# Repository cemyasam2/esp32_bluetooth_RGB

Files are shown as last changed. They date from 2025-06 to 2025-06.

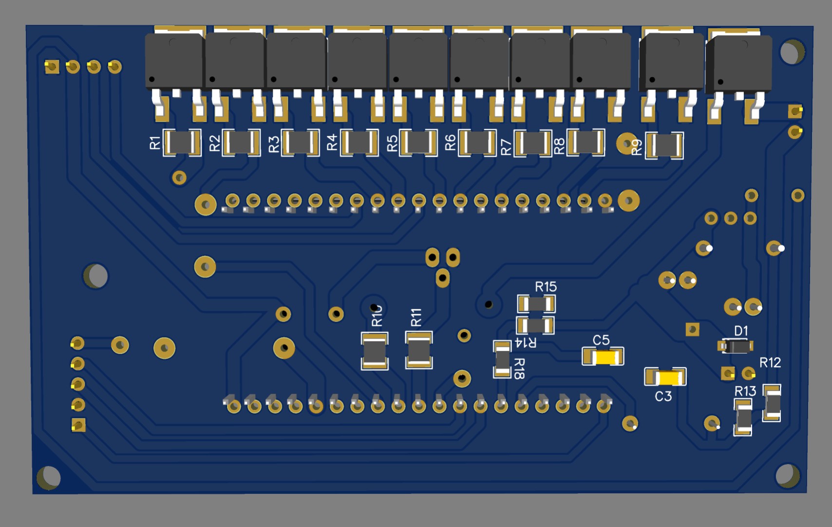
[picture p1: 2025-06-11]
boardback.jpg

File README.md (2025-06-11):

# 💡 esp32 LED Animasyon Projesi

Bu proje, esp32 kullanarak RGB LED’ler üzerinde animasyonlar oluşturur.  
Rotary encoder ile animasyonlar arasında geçiş yapılabilir. OLED ekran ve EEPROM desteği ile tam bir görsel deneyim sağlar! bluetooth üzerinden android telefonlar ile kontrol edilebnilir.
aşşagıdaki adresteki app ile kontrol edilebilir.

https://play.google.com/store/apps/details?id=easy.tech.rgbledcontrol&hl=tr

## 🎥 YouTube Videosu
👉 [Projeyi buradan izleyebilirsin](https://www.youtube.com/shorts/8XcT7dM-Kzo)

---

## 🔧 Kullanılan Malzemeler
-  ESP32
- 170cm RGB LED
- 1x Rotary Encoder
- 0.96" OLED Ekran (I2C)
- rotary encoder
- EEPROM (dahili)
- 3D baskı kutu (dosya eklidir)
ID	Name	Designator	Footprint	Quantity	Manufacturer Part	Manufacturer	Supplier	Supplier Part	Price
"1"	"10K"	"R16"	"R_AXIAL-0.4"	"1"	""	""	""	""	""
"2"	"1N4007"	"D2"	"DO-41_BD2.4-L4.7-P8.70-D0.9-RD"	"1"	"1N4007"	"SEMTECH"	"LCSC"	"C106903"	"0.019"
"3"	"H2"	"OLEDEKRAN"	"HDR-F-2.54_1X4"	"1"	""	""	"LCSC"	"C225501"	"0.077"
"4"	"H1"	"ROTARYSWITCH"	"HDR-F-2.54_1X5"	"1"	""	""	"LCSC"	"C50950"	"0.064"
"5"	"HDR-F-2.54_1x2"	"CHARGE_IN,POWER"	"HDR-F-2.54_1X2"	"2"	""	""	"LCSC"	"C49661"	"0.038"
"6"	"BC547"	"Q10"	"BC547"	"1"	""	""	""	""	""
"7"	"BUZZER"	"SG1"	"BUZZER-12MM"	"1"	""	""	""	""	""
"8"	"L7805"	"U1"	"L7803"	"1"	""	""	""	""	""
"9"	"ESP32 DEVKIT"	"U2"	"ESP32DEVKITCV4"	"1"	"ESP32 Dev Kit C V4"	"AZ-DELIVERY"	""	""	""
"10"	"200U"	"C1,C2"	"CAP-D6.3×F2.5"	"2"	""	""	""	""	""
"11"	"100NF"	"C3,C5"	"C1206"	"2"	""	""	""	""	""
"12"	"1N4007W"	"D1"	"SOD-123_L2.8-W1.8-LS3.7-RD"	"1"	"1N4007W"	"BLUE ROCKET"	"LCSC"	"C328592"	"0.008"
"13"	"22k"	"R12,R14"	"R1206"	"2"	""	""	""	""	""
"14"	"5k"	"R13,R15"	"R1206"	"2"	""	""	""	""	""
"15"	"10k"	"R18"	"R1206"	"1"	""	""	""	""	""
"16"	"1k"	"R1,R2,R3,R4,R5,R6,R7,R8,R9,R10,R11"	"R1210"	"11"	""	""	""	""	""
"17"	"NJVMJD122T4G"	"Q1,Q2,Q3,Q4,Q5,Q6,Q7,Q8,Q9,Q12"	"DPAK-3"	"10"	""	""	""	""	""

---

## 🧠 Özellikler
- Renk geçişli animasyonlar
- Encoder ile geçiş kontrolü
- EEPROM’a ayar kaydı
- Şarj durumu takibi
- OLED'de animasyon & pil simgeleri
- bluetooth kontrol

---

## 🖥️ Kod
Ana kod dosyasını `esp32_bluetooth_RGB_.ino` olarak yükleyebilirsin.  

---

## 🖨️ 3D Dosyalar
-[📦 STL dosyasını indir](difizor.stl)
-[📦 STL dosyasını indir](difizorbitis baslangic.stl)
-[📦 STL dosyasını indir](halka ek.stl)
-[📦 STL dosyasını indir](led tutucu.stl)
-[📦 STL dosyasını indir](rgb dikey lamba atma.stl)
-[📦 STL dosyasını indir](rotary tutucua.stl)
-[📦 STL dosyasını indir](taban kapak lamba.stl)
-[📦 STL dosyasını indir](taban.stl)

## 🔌 Devre Şeması
- topprint.pdf
- top.pdf
- back.pdf
- Gerber_rgbcubuk2_PCB_rgbcubuk2_2025-06-11.zip
- boardback.jpg
- boardfront.jpg
- BOM_rgbcubuk2_2025-06-11.csv
- PickAndPlace_PCB_rgbcubuk2_2025-06-11.csv

## 📄 Lisans
MIT Lisansı altında paylaşılmıştır. Dilediğiniz gibi kullanabilirsiniz.

---

## ☕ Destek Ol
Eğer projeyi beğendiysen, YouTube kanalıma abone olmayı unutma!  
[👉 TinkTime YouTube Kanalı](https://www.youtube.com/@cemyasamaka)

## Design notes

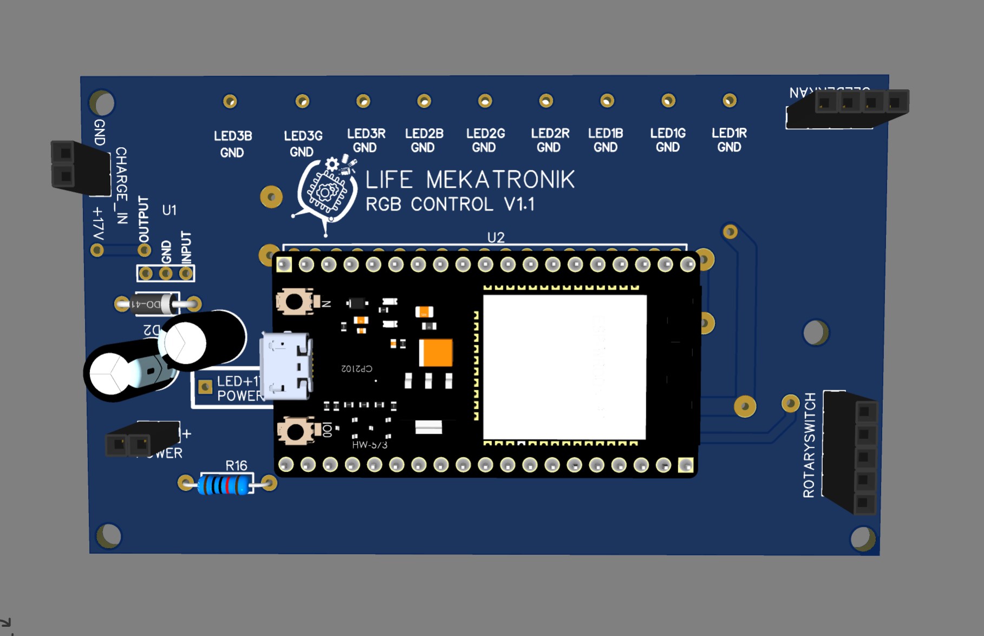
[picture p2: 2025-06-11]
boardfront.jpg

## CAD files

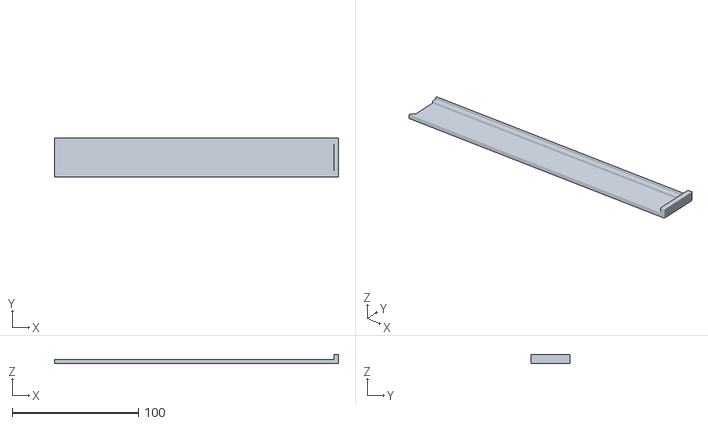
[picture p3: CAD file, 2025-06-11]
difizorbitis baslangic.stl
225.2 x 31.2 x 7.00

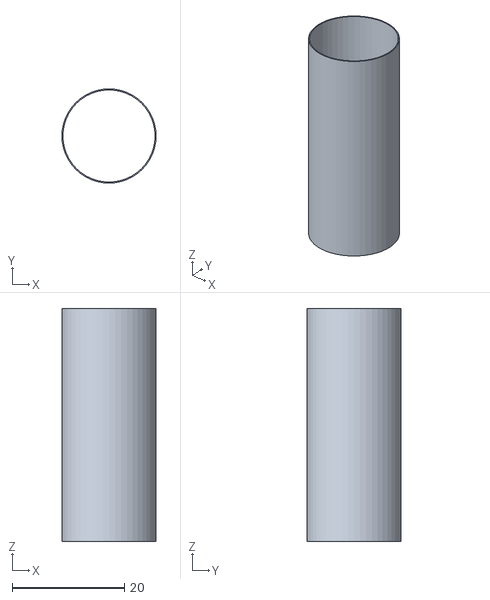
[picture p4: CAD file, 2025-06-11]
halka ek.stl
16.8 x 16.8 x 41.5

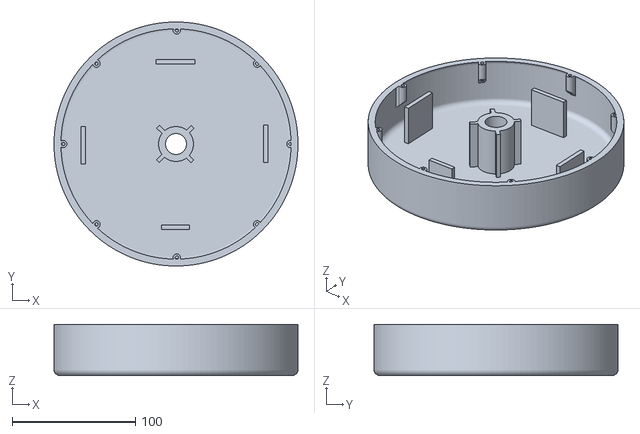
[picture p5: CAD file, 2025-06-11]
taban.stl
198.0 x 198.0 x 41.5

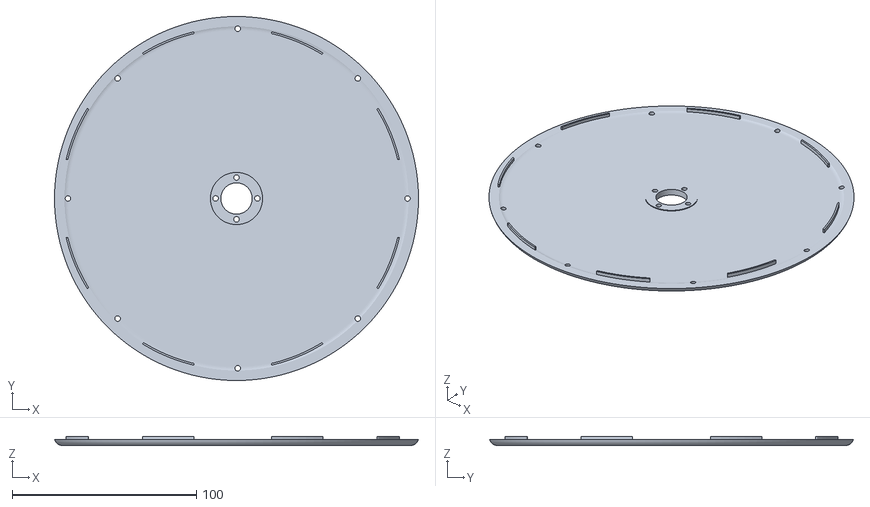
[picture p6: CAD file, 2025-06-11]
taban kapak lamba.stl
197.7 x 197.7 x 5.15

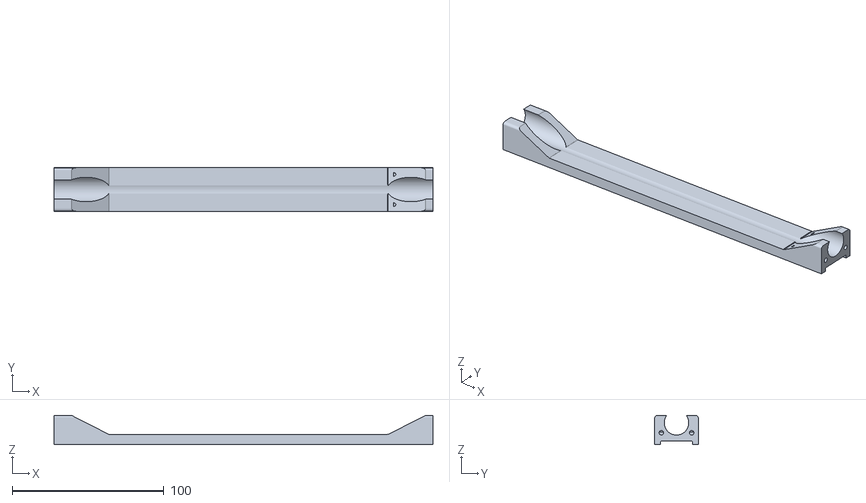
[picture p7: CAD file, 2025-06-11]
led tutucu.stl
250.0 x 28.7 x 19.4

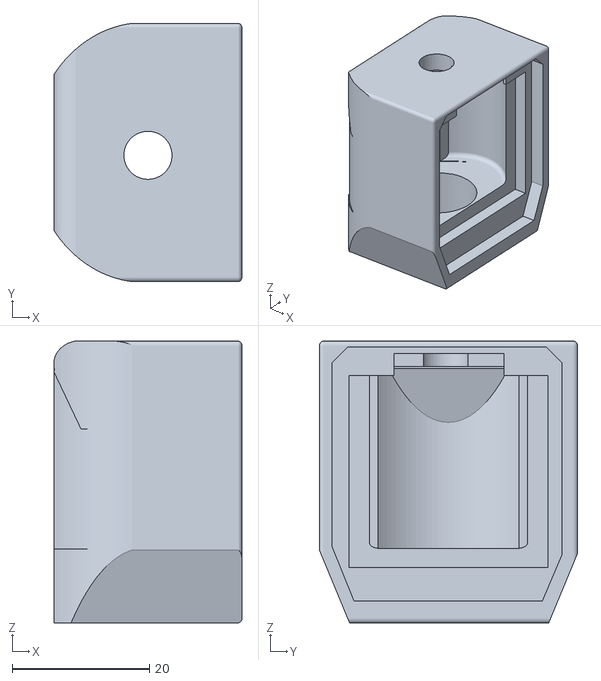
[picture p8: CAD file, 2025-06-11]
rotary tutucua.stl
27.4 x 37.6 x 41.1

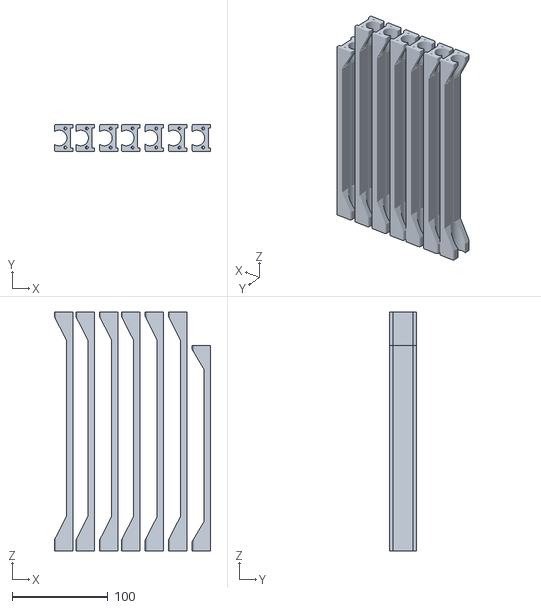
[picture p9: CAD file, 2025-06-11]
rgb dikey lamba atma.stl
163.5 x 28.7 x 250.0

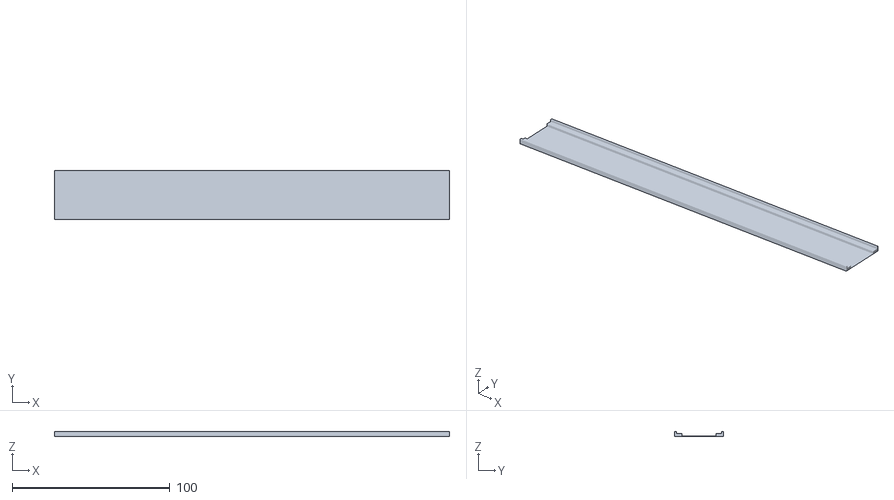
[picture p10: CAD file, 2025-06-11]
difizor.stl
250.2 x 31.2 x 3.24

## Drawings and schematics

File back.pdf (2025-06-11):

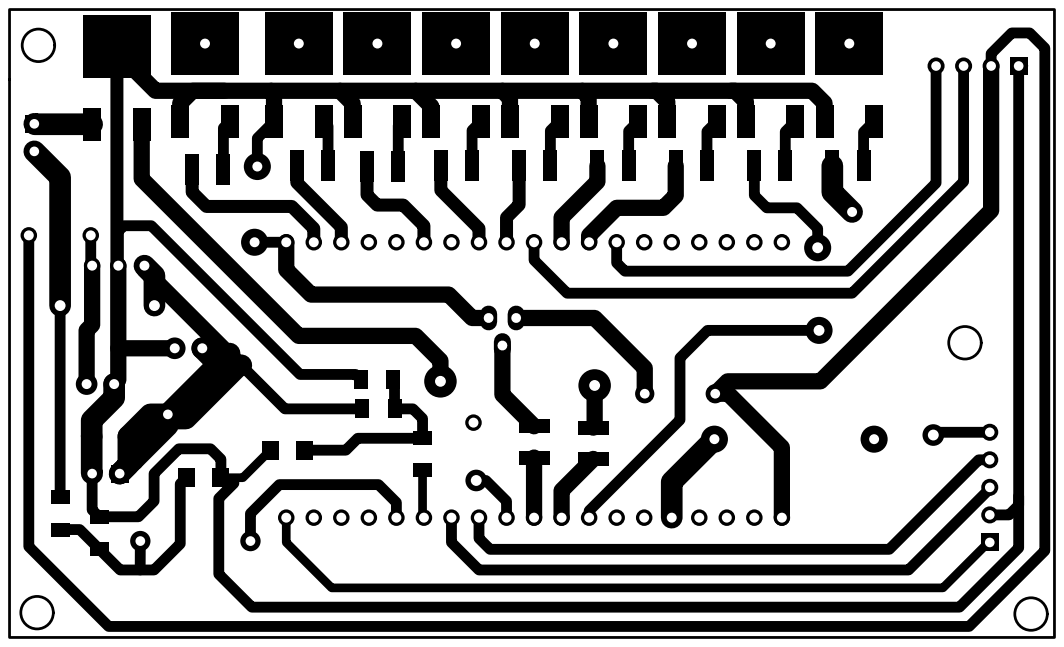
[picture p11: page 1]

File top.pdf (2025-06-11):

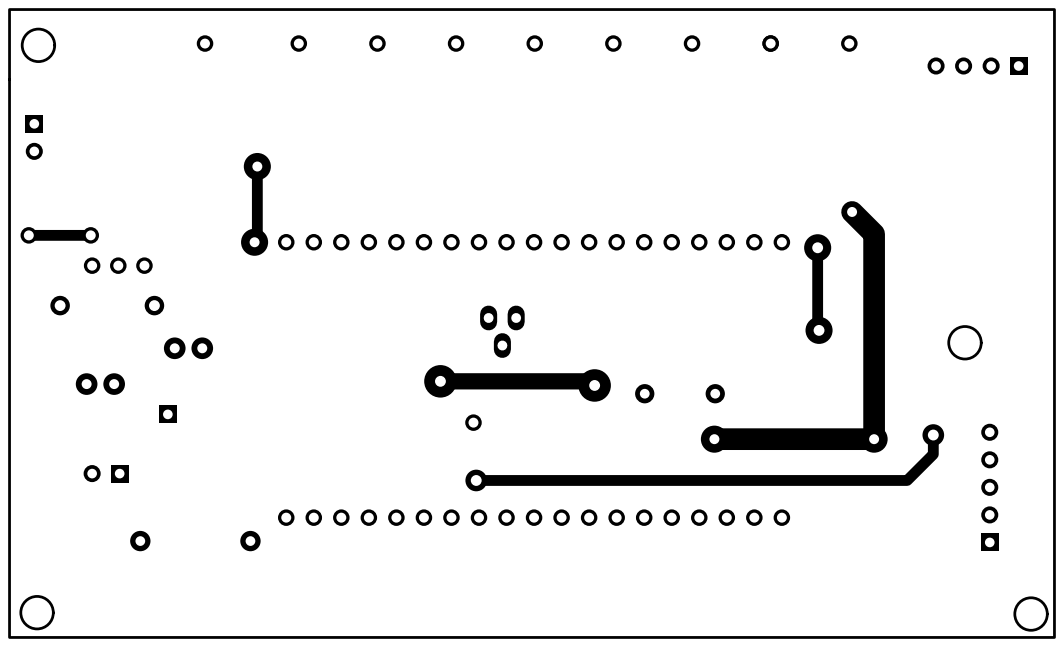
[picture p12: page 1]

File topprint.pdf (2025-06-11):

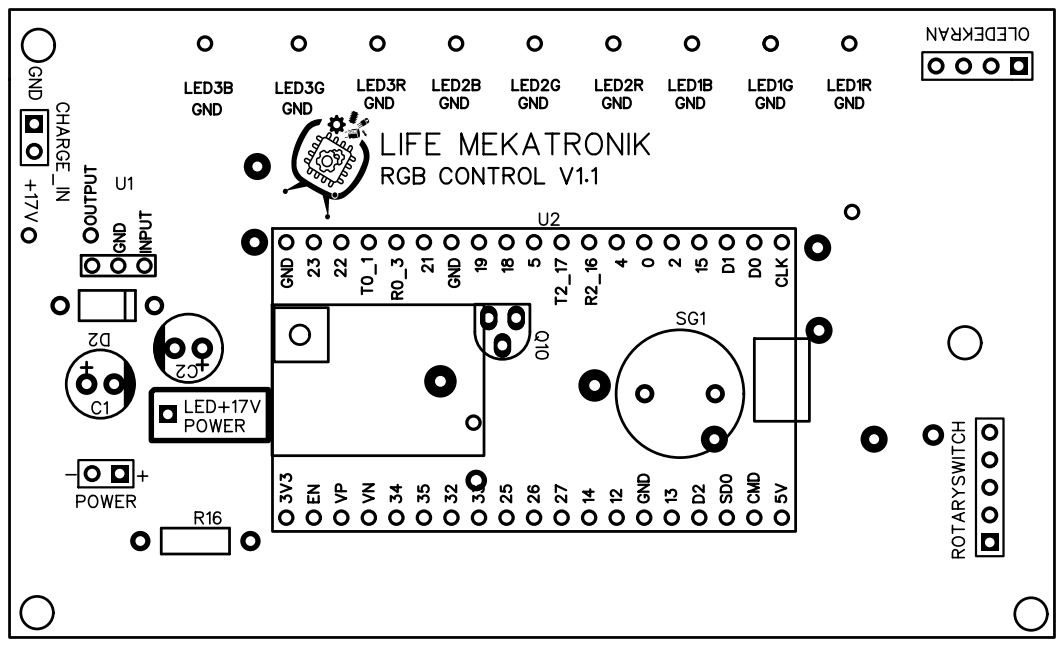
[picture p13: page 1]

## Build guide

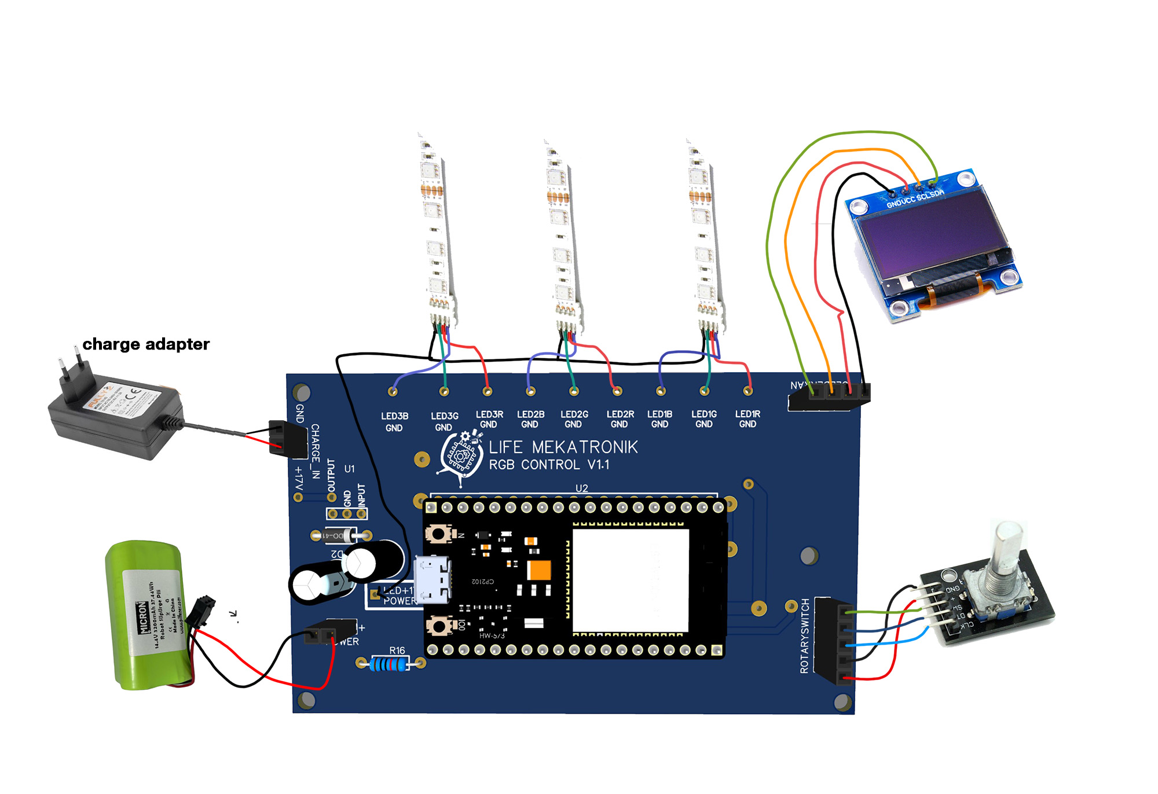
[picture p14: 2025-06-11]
wiring schema.jpg

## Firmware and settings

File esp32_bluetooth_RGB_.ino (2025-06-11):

#include <Wire.h>
#include <EEPROM.h>
#include <Adafruit_GFX.h>
#include <Adafruit_SSD1306.h>
#include "BluetoothSerial.h" // Bluetooth seri haberleşme kütüphanesi
// Wi-Fi ve OTA etkinlik kontrol değişkenleri
#define WIFI_ENABLED  0  // 1: WiFi açık,  0: WiFi kapalı

#if WIFI_ENABLED
#include <WiFi.h>
#include <WebServer.h>
#include <ElegantOTA.h>

// Wi-Fi ayarları
const char* ssid = "wifi ag adı yazın"; // Wi-Fi ağ adı
const char* password = "wifi şifrenizi yazın"; // Wi-Fi şifresi
// Sabit IP ayarları
IPAddress local_IP(192, 168, 1, 12);  // Sabit IP adresi
IPAddress gateway(192, 168, 1, 1);    // Ağ geçidi (genellikle router IP'si)
IPAddress subnet(255, 255, 255, 0);   // Alt ağ maskesi


WebServer server(80); // Web sunucusu 80 numaralı portt


#endif // WIFI_ENABLED


// === OLED ===
#define SCREEN_WIDTH 128
#define SCREEN_HEIGHT 64
#define OLED_SDA 4
#define OLED_SCL 5
Adafruit_SSD1306 display(SCREEN_WIDTH, SCREEN_HEIGHT, &Wire, -1);

// === PINLER ===
#define ENCODER_PIN_A 32
#define ENCODER_PIN_B 33
#define ENCODER_BUTTON 25
#define BUZZER_PIN 26
#define charge_on_of 27
#define BATTERY_ADC_PIN 35
#define LOW_VOLTAGE_THRESHOLD 11.0 // Batarya tipinize göre güncelleyin
#define CHARGE_ADC_PIN 34
#define CHARGE_PRESENT_THRESHOLD 3.0 // Gerilim bölücüye göre ayarla (adaptörün voltajını böldükten sonra bu pindeki voltaj eşiği)

const uint8_t pwmPins[3][3] = {
  {16, 14, 13}, {19, 18, 17}, {23, 22, 21}
};
const uint8_t pwmChannels[3][3] = {
  {2, 1, 0}, {5, 4, 3}, {8, 7, 6}
};

// === EEPROM ===
#define EEPROM_SIZE 7
int hueAddr[3] = {0, 2, 4};
int brightnessAddr[3] = {1, 3, 5};
#define GROUP_ADDR 6

// === Kontrol Değişkenleri ===
int animationSpeed = 30; // Genel animasyon hızı
int hue[3] = {0, 0, 0};
float brightness[3] = {1.0, 1.0, 1.0};
int selectedGroup = -1; // -1: Tümü, 0-2: Grup 1-3, 3-7: Animasyonlar, 8: Bluetooth Renk Modu

volatile int encoderPos = 0;
int lastEncoderPos = 0;
int lastEncoded = 0;
unsigned long lastEncoderTime = 0;
unsigned long lastDisplayUpdate = 0;
unsigned long lastRainbowUpdate = 0;
unsigned long buttonPressTime = 0;
bool buttonPressed = false;
bool longPressHandled = false;
bool longPressCandidate = false;

bool chargingDisplayActive = false; // Batarya şarj ekranı aktif mi?
bool chargingDisplaySuppressed = false; // Batarya şarj ekranı kullanıcı tarafından gizlendi mi?

// Animasyonlar için durum değişkenleri
unsigned long lastAnimationTime = 0;
int currentGroup = 0;         // Kayar animasyonlarda hangi grubun sırası
int currentColorPhase = 0; // Kayar animasyonlarda 0: Kırmızı, 1: Mavi, 2: Yeşil
const int ON = 255;         // On/Off modu için tam parlaklık
const int OFF = 0;          // On/Off modu için kapalı
const int MAX_BRIGHTNESS_VAL = 255; // İz bırakan animasyon için tam parlaklık
const int MIN_BRIGHTNESS_VAL = 0;   // İz bırakan animasyon için kapalı
const int FADE_STEP = 10;         // İz bırakan animasyonda sönme adım miktarı
const unsigned long FADE_INTERVAL = 3; // İz bırakma sönme hızı (ms)

// Her grubun o anki renk değerlerini tutan değişkenler (fade için önemli)
int currentRGB[3][3] = {{0, 0, 0}, {0, 0, 0}, {0, 0, 0}}; // [grup][kanal]

// İz bırakan animasyon için değişkenler
unsigned long lastFadeTime[3] = {0, 0, 0}; // Her grubun son sönme zamanı
bool fading[3] = {false, false, false};   // Her grup sönüyor mu?

// === Bluetooth ===
BluetoothSerial SerialBT;
bool isBluetoothConnected = false; // Bluetooth bağlantı durumu
bool bluetoothColorMode = false;   // Bluetooth ile renk ayarı yapılıp yapılmadığını takip et

// === Fonksiyon Prototipleri ===
void updateDisplay();
void applyAllColors();
void allGroupsOff();
void startFadeOut(int group);
void handleFading();
void setGroupColor(int group, int r, int g, int b);
void drawBatteryMiniIcon(int x, int y, float voltage, bool charging);
void drawBatteryWithFillBars(float voltage, bool charging); // Eğer charge_anim.h kullanmıyorsanız bunu yorum satırı yapın
void bluetoothCallback(const uint8_t *buffer, size_t len); // Bluetooth callback prototipi
void rgbToHsv(int r, int g, int b, int &h, float &s, float &v); // Yeni fonksiyon prototipi

// Pil Yüzdesi için Fonksiyon (Eksik olduğu için ekledim)
int getFillBarsFromVoltage(float voltage) {
  // Bu fonksiyonu kendi batarya voltaj aralıklarınıza göre doldurmanız gerekmektedir.
  // Örnek olarak NiMH için bir skala sunulmuştur:
  if (voltage >= 18) digitalWrite(charge_on_of, LOW);
  if (voltage >= 17.6) return 10; // Tam dolu (max 10 bar)
  else if (voltage >= 17.2) return 9; digitalWrite(charge_on_of, HIGH);
  else if (voltage >= 17.0) return 8; digitalWrite(charge_on_of, HIGH);
  else if (voltage >= 16.5) return 7; digitalWrite(charge_on_of, HIGH);
  else if (voltage >= 15.0) return 6; digitalWrite(charge_on_of, HIGH);
  else if (voltage >= 14.0) return 5; digitalWrite(charge_on_of, HIGH);
  else if (voltage >= 13.0) return 4; digitalWrite(charge_on_of, HIGH);
  else if (voltage >= 12.0) return 3; digitalWrite(charge_on_of, HIGH);
  else if (voltage >= 11.0) return 2; digitalWrite(charge_on_of, HIGH);
  else if (voltage >= 10.0) return 1; digitalWrite(charge_on_of, HIGH); // Düşük pil
  else return 0; // Boş
}


void IRAM_ATTR readEncoder() {
  int MSB = digitalRead(ENCODER_PIN_A);
  int LSB = digitalRead(ENCODER_PIN_B);
  int encoded = (MSB << 1) | LSB;
  int transition = (lastEncoded << 2) | encoded;

  if (millis() - lastEncoderTime > 2) {
    if (transition == 0b0001 || transition == 0b0111 || transition == 0b1110 || transition == 0b1000)
      encoderPos++;
    else if (transition == 0b0010 || transition == 0b0100 || transition == 0b1101 || transition == 0b1011)
      encoderPos--;

    lastEncoded = encoded;
    lastEncoderTime = millis();
  }
}

int getNiMHBatteryPercentage(float voltage) {
  // Bu değerleri kendi batarya tipinize göre güncelleyin!
  // Örneğin, 4S NiMH için 4.8V nominal, 5.8V tam dolu
  // Bu aralıklar çok yüksek görünüyor, muhtemelen 12V kurşun asit veya çok hücreli NiMH.
  if (voltage >= 17.0) return 100;
  else if (voltage >= 16.5) return 90;
  else if (voltage >= 16.0) return 80;
  else if (voltage >= 15.5) return 70;
  else if (voltage >= 15.0) return 60;
  else if (voltage >= 14.5) return 50;
  else if (voltage >= 14.0) return 40;
  else if (voltage >= 13.5) return 30;
  else if (voltage >= 13.0) return 20;
  else return 10;
}

float readChargeVoltage() {
  int raw = analogRead(CHARGE_ADC_PIN);
  float voltage = raw / 4095.0 * 3.3;
  return voltage * (22.0 + 4.7) / 4.7; // Oran senin R1/R2 değerlerine göre (voltaj bölücü)
}

bool isChargingPluggedIn() {
  float v = readChargeVoltage();
  return v > CHARGE_PRESENT_THRESHOLD; // Bu eşiği adaptörünüze göre ayarlayın
}

float readBatteryVoltage() {
  int raw = analogRead(BATTERY_ADC_PIN);
  float voltage = raw / 4095.0 * 3.3;
  return voltage * (22.0 + 4.7) / 4.7; // Gerilim bölücü R1=22k, R2=4.7k için
}

void setupPWM(uint8_t pin, uint8_t channel) {
  ledcSetup(channel, 5000, 8); // 5 kHz frekans, 8 bit çözünürlük
  ledcAttachPin(pin, channel);
}



void hsvToRgb(int h, float v, int &r, int &g, int &b) {
  float s = 1.0; // Saturasyon genellikle tam dolu (1.0) tutulur
  float C = s * v;
  float X = C * (1 - abs(fmod(h / 60.0, 2) - 1));
  float m = v - C;
  float r1, g1, b1;
  if (h < 60)         { r1 = C; g1 = X; b1 = 0; }
  else if (h < 120){ r1 = X; g1 = C; b1 = 0; }
  else if (h < 180){ r1 = 0; g1 = C; b1 = X; }
  else if (h < 240){ r1 = 0; g1 = X; b1 = C; }
  else if (h < 300){ r1 = X; g1 = 0; b1 = C; }
  else           { r1 = C; g1 = 0; b1 = X; }
  r = (r1 + m) * 255;
  g = (g1 + m) * 255;
  b = (b1 + m) * 255;
}

// Yeni RGB'den HSV'ye dönüşüm fonksiyonu
void rgbToHsv(int r, int g, int b, int &h, float &s, float &v) {
  float fr = r / 255.0; // 0-1 aralığına normalize et
  float fg = g / 255.0;
  float fb = b / 255.0;

  float cmax = max(max(fr, fg), fb);
  float cmin = min(min(fr, fg), fb);
  float delta = cmax - cmin;

  if (delta == 0) {
    h = 0; // Renk yok, gri ton
  } else if (cmax == fr) {
    h = (int)(60 * fmod(((fg - fb) / delta), 6));
  } else if (cmax == fg) {
    h = (int)(60 * (((fb - fr) / delta) + 2));
  } else {
    h = (int)(60 * (((fr - fg) / delta) + 4));
  }
  if (h < 0) h += 360; // Negatif hue değerlerini düzelt

  s = (cmax == 0) ? 0 : delta / cmax; // Saturasyon
  v = cmax; // Value/Brightness (parlaklık)
}


void setGroupColor(int group, int r, int g, int b) {
  ledcWrite(pwmChannels[group][0], r); // Kırmızı
  ledcWrite(pwmChannels[group][1], g); // Yeşil
  ledcWrite(pwmChannels[group][2], b); // Mavi
  currentRGB[group][0] = r; // Mevcut durumu kaydet
  currentRGB[group][1] = g;
  currentRGB[group][2] = b;
}

// Tüm grupları kapatır
void allGroupsOff() {
  for (int g = 0; g < 3; g++) {
    setGroupColor(g, OFF, OFF, OFF);
  }
}

// Bir grubu sönmeye başlatır (bloklamaz)
void startFadeOut(int group) {
  fading[group] = true;
  lastFadeTime[group] = millis(); // Sönmenin başladığı zamanı kaydet
}

// Tüm sönme işlemlerini yöneten, loop içinde çağrılması gereken fonksiyon
void handleFading() {
  unsigned long currentTime = millis();
  for (int group = 0; group < 3; group++) {
    if (fading[group] && currentTime - lastFadeTime[group] >= FADE_INTERVAL) {
      lastFadeTime[group] = currentTime; // Bir sonraki sönme adımının zamanını güncelle

      int r = currentRGB[group][0];
      int g = currentRGB[group][1];
      int b = currentRGB[group][2];

      if (r > MIN_BRIGHTNESS_VAL || g > MIN_BRIGHTNESS_VAL || b > MIN_BRIGHTNESS_VAL) {
        if (r > MIN_BRIGHTNESS_VAL) r = max(r - FADE_STEP, MIN_BRIGHTNESS_VAL);
        if (g > MIN_BRIGHTNESS_VAL) g = max(g - FADE_STEP, MIN_BRIGHTNESS_VAL);
        if (b > MIN_BRIGHTNESS_VAL) b = max(b - FADE_STEP, MIN_BRIGHTNESS_VAL);
        setGroupColor(group, r, g, b); // Yeni, azaltılmış renk değerini uygula
      } else {
        fading[group] = false; // Tamamen söndü, sönmeyi durdur
        setGroupColor(group, MIN_BRIGHTNESS_VAL, MIN_BRIGHTNESS_VAL, MIN_BRIGHTNESS_VAL); // Tamamen kapalı olduğundan emin ol
      }
    }
  }
}

void applyGroupColor(int i) {
  int r, g, b;
  hsvToRgb(hue[i], brightness[i], r, g, b);
  setGroupColor(i, r, g, b); // Artık setGroupColor fonksiyonu currentRGB'yi güncelliyor
}

void applyAllColors() {
  for (int i = 0; i < 3; i++) applyGroupColor(i);
}

void beepGroup(int count) {
  for (int i = 0; i < count; i++) {
    tone(BUZZER_PIN, 2000, 100);
    delay(200);
  }
}

void updateDisplay() {
  display.clearDisplay();

  display.setTextSize(1);
  display.setTextColor(SSD1306_WHITE);

  // Mod başlığı (Tümü, Grup 1, Grup 2, Grup 3) her zaman üst satırda
  display.setCursor(0, 0);
  display.print("Mod:");
  display.setCursor(30, 0); // Mod adını Mod: yazısının sağına alıyoruz
  if (selectedGroup == -1) display.println("Tumu");
  else if (selectedGroup == 0) display.println("Grup 1");
  else if (selectedGroup == 1) display.println("Grup 2");
  else if (selectedGroup == 2) display.println("Grup 3");
  // Animasyon modları için başlıkları bir alt satıra alıyoruz
  else if (selectedGroup == 3) display.println("Rainbow");
  else if (selectedGroup == 4) display.println("Rand. Rainbow");
  else if (selectedGroup == 5) display.println("Fade Loop");
  else if (selectedGroup == 6) display.println("ON/OFF Kayma");
  else if (selectedGroup == 7) display.println("Iz Birakan");
  else if (selectedGroup == 8) display.println("BT Renk"); // Yeni: Bluetooth renk modu
  else if (selectedGroup == -2) display.println("Kapali"); // Bluetooth ile kapatildi

  // Animasyon hızını göster (sadece animasyon modlarında ve alt satırda)
  if (selectedGroup >= 3 && selectedGroup <= 7) {
    display.setCursor(0, 16); // Mod başlığından 2 satır alta in (8+8)
    display.printf("Hiz: %d ms", animationSpeed);
  }

  // LED gruplarının renk ve parlaklık bilgisi (sadece normal modlarda ve BT Renk modunda)
  if (selectedGroup < 3 || selectedGroup == -1 || selectedGroup == 8) { // Normal hue/brightness modları veya BT Renk modu
    for (int i = 0; i < 3; i++) {
      display.setCursor(0, 16 + i * 16); // İlk gruptan itibaren 16 piksel boşluk
     display.printf("G%d H:%3d B:%3d%%", i + 1, hue[i], int(brightness[i] * 100));
    }
  }

  // Şarj durumu varsa sağ üst köşeye ikonu çiz
  if (isChargingPluggedIn()) {
    float batVoltage = readBatteryVoltage();
    drawBatteryMiniIcon(SCREEN_WIDTH - 14, 0, batVoltage, true);
  }else  if (!isChargingPluggedIn()) {
    float batVoltage = readBatteryVoltage();
    drawBatteryMiniIcon(SCREEN_WIDTH - 14, 0, batVoltage, false);
  }

  // Bluetooth bağlantı durumu
  if (isBluetoothConnected) {
    display.setCursor(0, SCREEN_HEIGHT - 8); // En alt satırda
    display.print("BT Bagli");
  }

  display.display();
}
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
void loop() {
  unsigned long currentTime = millis(); // Loop'un başında zamanı bir kez al

  // Bluetooth bağlantı durumunu kontrol et
  static bool prevBluetoothConnected = false;
  // BluetoothSerial kütüphanesinin farklı versiyonları için uyumluluk kontrolü
  #if defined(ESP_IDF_VERSION_MAJOR) && ESP_IDF_VERSION_MAJOR >= 4 // ESP-IDF 4.x ve üzeri
    isBluetoothConnected = SerialBT.hasClient();
  #else // Daha eski ESP-IDF versiyonları veya Arduino ESP32 core'u
    isBluetoothConnected = SerialBT.connected();
  #endif


  if (isBluetoothConnected != prevBluetoothConnected) {
    updateDisplay(); // Bağlantı durumu değişince ekranı güncelle
    prevBluetoothConnected = isBluetoothConnected;
    if (isBluetoothConnected) {
      Serial.println("Bluetooth baglandi!");
    } else {
      Serial.println("Bluetooth baglantisi kesildi.");
    }
  }


  bool charging = isChargingPluggedIn();

  // Şarj takıldıysa VE daha önce kullanıcı tarafından gizlenmediyse şarj ekranını göster
  if (charging && !chargingDisplaySuppressed) {
    sarz_oluyor();
    return; // sarz_oluyor fonksiyonu bloke edici olduğu için burada return yapıyoruz
  }

  // Eğer artık şarjda değilse (kablo çekildiyse), gizleme bayrağını sıfırla
  if (!charging && chargingDisplaySuppressed) {
    chargingDisplaySuppressed = false; // Şarj kablosu çekildi, ekran gizleme sıfırlandı
    Serial.println("Şarj kablosu çekildi, ekran gizleme sıfırlandı.");
  }

  static bool btnPrevState = HIGH;
  bool btnState = digitalRead(ENCODER_BUTTON);

  // Rotary Encoder Okuma ve Ayar (Bluetooth ile kontrol edildiğinde devre dışı kalabilir veya öncelik verilebilir)
  // Şimdilik, Bluetooth bağlı olsa bile encoder çalışmaya devam edecek.
  if (encoderPos != lastEncoderPos) {
    int diff = encoderPos - lastEncoderPos;
    lastEncoderPos = encoderPos;

    if (digitalRead(ENCODER_BUTTON) == LOW) { // Buton basılıyken genel parlaklık ayarı
      if (selectedGroup == -1 || selectedGroup > 2 || selectedGroup == 8) { // BT renk modu için de geçerli
        float newLevel = constrain(brightness[0] + diff * 0.02, 0.0, 1.0);
        for (int i = 0; i < 3; i++) brightness[i] = newLevel;
      } else {
        brightness[selectedGroup] = constrain(brightness[selectedGroup] + diff * 0.02, 0.0, 1.0);
      }
    } else { // Buton basılı değilse:
      if (selectedGroup >= 3 && selectedGroup <= 7) { // Animasyon modları (3, 4, 5, 6, 7) için hız ayarı
        animationSpeed = constrain(animationSpeed - diff * 2, 10, 500); // 10ms-500ms arası
        Serial.printf("Animasyon Hizi: %dms\n", animationSpeed);
      } else { // Diğer modlarda renk ayarı (-1, 0, 1, 2, 8)
        if (selectedGroup == -1 || selectedGroup == 8) { // "Tümü" veya "BT Renk" modu için hue ayarı
          for (int i = 0; i < 3; i++) hue[i] = (hue[i] + diff * 5 + 360) % 360;
        } else if (selectedGroup >= 0 && selectedGroup <= 2) { // Tek grup için hue ayarı
          hue[selectedGroup] = (hue[selectedGroup] + diff * 5 + 360) % 360;
        }
      }
    }
    // Animasyon modları dışındaki durumlarda renkleri hemen uygula
    if (selectedGroup < 3 || selectedGroup == -1 || selectedGroup == 8) { // BT renk modunda da hemen uygula
      applyAllColors();
    }
    updateDisplay(); // Hız değişince OLED'i hemen güncelle
    saveSettingsToEEPROM(); // Ayarları kaydet
  }

  // Butona basılı tutma veya tıklama
  // Normal çalışma modunda buton basımını dinle (şarj ekranı aktif değilse)
  if (!chargingDisplayActive) {
    if (btnPrevState == HIGH && btnState == LOW) {
      buttonPressTime = currentTime;
    }
    if (btnPrevState == LOW && btnState == HIGH) {
      unsigned long duration = currentTime - buttonPressTime;
      if (duration >= 800) {
        // Uzun basış: parlaklık ayarı (aynı kaldı)
        int startEncoder = encoderPos;
        int currentEncoder = encoderPos;
        while (digitalRead(ENCODER_BUTTON) == LOW) { // Buton hala basılıyken
          if (encoderPos != currentEncoder) {
            int diff = encoderPos - currentEncoder;
            currentEncoder = encoderPos;
            if (selectedGroup == -1 || selectedGroup > 2 || selectedGroup == 8) { // BT renk modu için de geçerli
              for (int i = 0; i < 3; i++)
                brightness[i] = constrain(brightness[i] + diff * 0.02, 0.0, 1.0);
            } else {
              brightness[selectedGroup] = constrain(brightness[selectedGroup] + diff * 0.02, 0.0, 1.0);
            }
            applyAllColors();
            updateDisplay();
            saveSettingsToEEPROM();
          }
          delay(50); // Buton basılı tutulurken küçük bir gecikme
        }
      } else {
        // Kısa tıklama: grup/mod geçişi
        selectedGroup++;
        if (selectedGroup > 8) selectedGroup = -1; // Toplam 9 mod var (-1'den 8'e)
        
        bluetoothColorMode = false; // Manuel geçişlerde BT renk modundan çık

        // Yeni animasyon moduna geçildiğinde animasyon değişkenlerini sıfırla ve LED'leri kapat
        if (selectedGroup >= 6 && selectedGroup <= 7) {
            currentGroup = 0;
            currentColorPhase = 0;
            lastAnimationTime = currentTime; // Animasyonu hemen başlat
            allGroupsOff(); // Önceki durumdan kalma yanık LED olmasın

            // İz bırakan animasyon için sönme durumlarını sıfırla
            for(int i = 0; i < 3; i++) {
                fading[i] = false;
                lastFadeTime[i] = 0;
            }
        }

        if (selectedGroup == -1) { // "Tümü" moduna geçildiğinde tüm grupların renklerini ve parlaklıklarını eşitle
            // Başlangıçta EEPROM'dan okunan ilk grubun hue ve parlaklığını referans al
            int referenceHue = map(EEPROM.read(hueAddr[0]), 0, 255, 0, 360);
            float referenceBrightness = (float)EEPROM.read(brightnessAddr[0]) / 255.0;
            for (int i = 0; i < 3; i++) {
                hue[i] = referenceHue;
                brightness[i] = referenceBrightness;
            }
            applyAllColors(); // Renkleri hemen uygula
        } else if (selectedGroup < 6 || selectedGroup == 8) { // Animasyon modlarından çıkıldığında veya BT renk modunda renkleri geri uygula
            applyAllColors();
        }

        beepGroup(1); // Mod değişiminde kısa bip
        updateDisplay();
        saveSettingsToEEPROM();
      }
    }
  }
  btnPrevState = btnState;


  // --- Animasyon Modları ---

  // Rainbow, Offset Rainbow ve Fade Loop modları (mevcut)
  if ((selectedGroup >= 3 && selectedGroup <= 5) && currentTime - lastRainbowUpdate > animationSpeed) {
    if (selectedGroup == 3) {
      static int hueVal = 0;
      hueVal = (hueVal + 3) % 360;
      for (int i = 0; i < 3; i++) hue[i] = hueVal;
      applyAllColors();
    } else if (selectedGroup == 4) {
      static int baseHue = 0;
      int offsets[3] = {0, 120, 240};
      baseHue = (baseHue + 3) % 360;
      for (int i = 0; i < 3; i++) hue[i] = (baseHue + offsets[i]) % 360;
      applyAllColors();
    } else if (selectedGroup == 5) {
      static int groupIndex = 0;
      static bool fadeIn = true;
      static float step = 0.05;
      float maxBrightness = EEPROM.read(brightnessAddr[0]) / 255.0;
      if (maxBrightness < 0.1) maxBrightness = 0.3; // Minimum parlaklık eşiği

      if (fadeIn) {
        brightness[groupIndex] += step;
        if (brightness[groupIndex] >= maxBrightness) {
          brightness[groupIndex] = maxBrightness;
          fadeIn = false;
        }
      } else {
        brightness[groupIndex] -= step;
        if (brightness[groupIndex] <= 0.0) {
          brightness[groupIndex] = 0.0;
          fadeIn = true;
          groupIndex = (groupIndex + 1) % 3;
        }
      }
      applyAllColors();
    }
    lastRainbowUpdate = currentTime;
  }
  
  // 7. Efekt: Kesintisiz On/Off Kayma (selectedGroup == 6)
  if (selectedGroup == 6 && currentTime - lastAnimationTime >= animationSpeed) {
    lastAnimationTime = currentTime; // Zamanı sıfırla

    allGroupsOff(); // Önceki LED'i kapat

    // Sıradaki LED'i yak
    if (currentColorPhase == 0) { // Kırmızı Kayma
      setGroupColor(currentGroup, ON, OFF, OFF);
    } else if (currentColorPhase == 1) { // Mavi Kayma
      setGroupColor(currentGroup, OFF, OFF, ON);
    } else { // Yeşil Kayma
      setGroupColor(currentGroup, OFF, ON, OFF);
    }

    // Bir sonraki adıma geç
    currentGroup++;
    if (currentGroup >= 3) { // Tüm grupları geçtiysek
      currentGroup = 0;       // Başa dön
      currentColorPhase++;    // Bir sonraki renge geç
      if (currentColorPhase >= 3) { // Tüm renkleri geçtiysek
        currentColorPhase = 0;    // Başa dön (Kırmızıdan tekrar başla)
      }
    }
  }

  // 8. Efekt: İz Bırakan Kayma (selectedGroup == 7)
  if (selectedGroup == 7) {
    // Sönmekte olan LED'leri yönet
    handleFading();
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
